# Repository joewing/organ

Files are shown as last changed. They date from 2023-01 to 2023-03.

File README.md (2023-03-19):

# 3D Printed Polyphonic Organ

## Features
  * Full-size 3D printed keyboard
  * 8-way polyphony
  * 9 drawbars to adjust harmonics (like a Hammond organ)
  * Sustain pedal
  * Range C0 through B7 (96 notes)

## Directories
  * src - Source code for the microcontroller (AVR ATtiny861A)
  * pcb/sensor - PCB for the key sensor board
  * pcb/controller PCB for the controller board
  * scad - OpenSCAD design

## Function Keys

Holding the "function" key on the controller PCB switches into
function mode.

### Tuning

Since we use the on-board oscillator, it is necessary to tune the
clock frequency to make the notes in tune. This tuning is stored in
EEPROM.

  * F#0 - Flatten
  * G#0 - Reset
  * A#0 - Sharpen

## 3D Printed Parts

  * Keybed
  * White keys (7)
  * Black keys (5)
  * Assembly tool (to help attach the rubber bands)
  * Control board holder

The sensor PCB is snapped into the keybed and the keys are attached,
one at a time along with the rubber band to pull the key up. Multiple
keybeds can be attached together using zipties (there are holes for
zipties in the standoff for the keys).

## BOM

  * Controller PCB
    * 1x ATtiny861A
    * 1x USB-B socket
    * 1x 2x3 IDC socket
    * 1x 3.5mm audio jack
    * 1x 3mm LED
    * 1x 6mm SPST tactile switch
    * 10x 10k linear POT
    * 2x 1k resistor
    * 12x 0.1u capacitor
    * 1x 10u capacitor
    * 1x 47u capacitor
    * 1x 6-pin right-angle socket

  * Sensor PCB (1 per octave)
    * 12x 12.6x6.5x5.7mm SPDT limit switch
    * 2x 10k resistor
    * 2x 74HC165
    * 2x 0.1uF capacitor
    * 1x 6-pin right-angle socket
    * 1x 6-pin right-angle pin header

  * Other
    * 12x small rubber bands (one set per octave)
    * USB cord and power supply

## Keys

Each note is controlled by a limit switch. The output of the limit
switches are processed serially using two 74HC165 8-bit parallel input
shift registers per octave. Since there are only 12 notes in an octave
4 bits are wasted for simplicity. Using this shift register interface,
we can read all keys using only 3 pins of the microcontroller.

In software, the state of each key is recorded in a bitmap. When a new key
press is detected, a "voice" is removed from the head of a linked list
and placed at the end of the list. The frequency increment is set
according to the index of the key that was pressed. The frequency increment
is a 16-bit value used to move through the waveform every time the
sample interrupt executes. The top 8 bits are used as an index into
the 256 entry waveform.

When a key release is detected, the "voice" is removed and placed at the
head of the list and the frequency increment is set to 0 to prevent the
sample interrupt from moving through the waveform.
The linked list is used so that the least recently pressed key is
re-used if there are too many keys pressed at the same time.

Finally, the sustain pedal simply prevents the processing of key releases.

## Drawbars

There are nine drawbars (potentiometers) that are sampled using the 
multiplexed ADC. One drawbar is sampled per iteration of the main loop.
We track the quantized value of each drawbar. When a change is
detected, its value is recorded and the waveform is recomputed.

## Waves

Waveforms are generated by sampling a 256 point sine wave.
The base waveform is at half the fundamental frequency (16')
allowing us to generate the necessary harmonics by stepping
through the sine wave at different rates:

  * 16'     - Sub-Octave (1x)
  * 5 1/3'  - Quint (3x)
  * 8'      - Principal (2x)
  * 4'      - Octave (4x)
  * 2 2/3'  - Nazard (6x)
  * 2'      - Super Octave (8x)
  * 1 3/5'  - Tierce (10x)
  * 1 1/3'  - Larigot (12x)
  * 1'      - Super-Super Octave (16x)

When a drawbar is changed, the waveform is recomputed by adding
together the scaled contributions from each drawbar. Each
contribution is determined by stepping through the sine wave at the
specified rate (2 for 8', etc), wrapping around when necessary,
and scaling the amplitude by the drawbar level. The final waveform
is scaled down by the max total contribution.
The waveform itself is stored as 256 8-bit values.

Audio is generated using 64 MHz pulse-width modulation. The duty cycle
is configured to have 256 levels, leaving an output frequency of 250 kHz,
which is well above the audio range and easy to filter. The duty cycle is
determined by adding together the waveform contributions from each voice.
Since there are 8 voices and the duty cycle is controlled by
an 8-bit value, we get 5 bits of resolution (this avoids overflow in
the case all voices are at the maximum position in the waveform at
the same time).
A 20 kHz timer interrupt causes us to move through the waveforms
for each voice and update the PWM duty cycle.

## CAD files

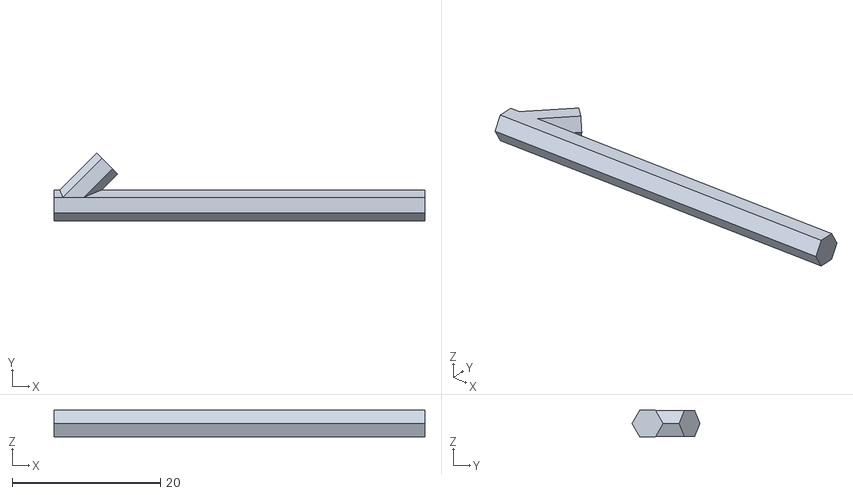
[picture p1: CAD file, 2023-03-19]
scad/tool.stl
50.0 x 9.17 x 3.64

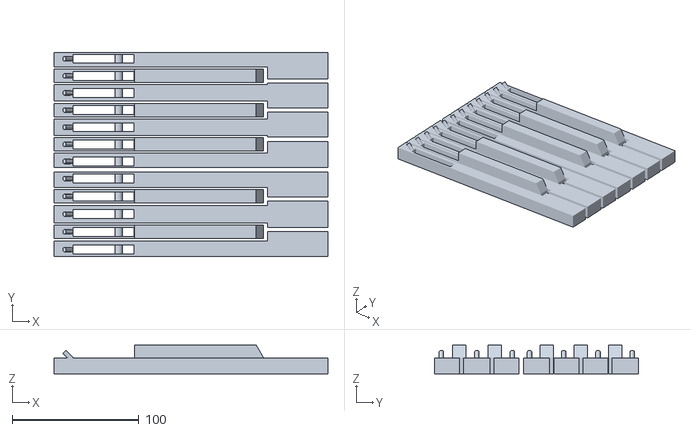
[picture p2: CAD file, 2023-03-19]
scad/keys.stl
216.0 x 160.8 x 22.9

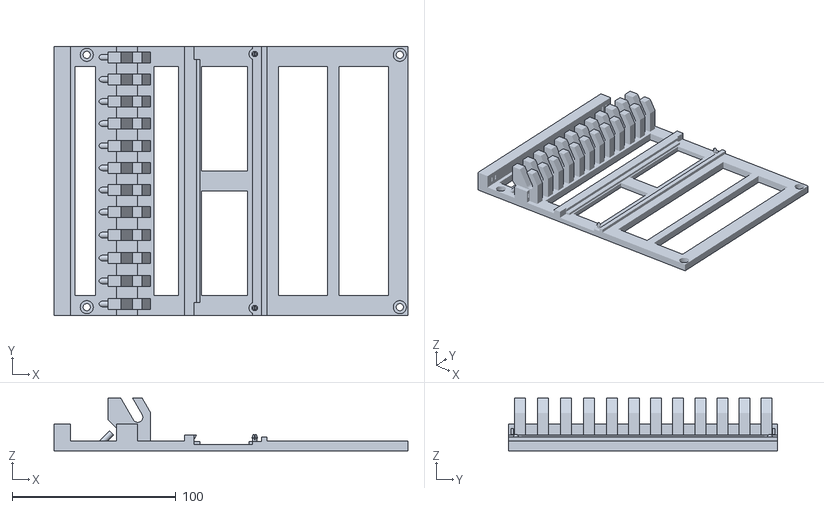
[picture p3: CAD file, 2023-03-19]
scad/bed.stl
216.0 x 164.0 x 32.3

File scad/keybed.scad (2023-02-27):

OUTPUT_KEYS = 0;
OUTPUT_BED = 1;
OUTPUT_BACK = 0;
OUTPUT_CONTROL = 0;
OUTPUT_TOOL = 0;

key_spacing = 3.2;
base_width = 164;

black_key_width = 14;
white_key_length = 216;
black_key_length = white_key_length - 2 * 25.4;
white_key_height = 0.5 * 25.4;
black_key_height = white_key_height + 0.4 * 25.4;
bed_height = 6;
bed_length = white_key_length;
joint_offset = 150;
screw_head_radius = 2.8;
screw_head_height = 3;
screw_hole_radius = 1.4;
pcb_length = 40;
pcb_thickness = 1.6;
pcb_mount_height = 2;
pcb_standoff_height = pcb_mount_height;
hinge_y = white_key_length - 54 + 3;
hinge_z = 4;
hinge_radius = 3;
pcb_offset = 90;
middle_hole_offset = 196;
key_elevation = 10.6;
bed_zoffset = -key_elevation - 0.2;
stop_height = white_key_height + key_elevation + 3;
cutout_width = 7;

white_key_widths = [23, 24, 23, 24, 23, 23, 24];
black_key_offsets = [14, 42, 83, 110, 137];

back_widths = [14, 14, 14, 14, 14, 13, 14, 13, 14, 13, 14, 13];

function white_key_offset(i) = i == 0 ? 0 : white_key_offset(i - 1) + white_key_widths[i - 1];

function back_offset(i) = i == 0 ? 0 : back_offset(i - 1) + back_widths[i - 1];

module stabilizer(i) {
    x = back_offset(i);
    w = back_widths[i];
    translate([x + w / 2 - cutout_width / 2, white_key_length - 63, -1]) { 
        cube([cutout_width, 48, black_key_height + 2]);
    }
}

module key_hinge(i) {
    x = back_offset(i);
    w = back_widths[i];
    translate([x + key_spacing / 2, hinge_y, hinge_z - 0.4]) {
        rotate([0, 90, 0]) {
            cylinder(w - key_spacing, hinge_radius, hinge_radius, $fn=64);
        }
    }
}

module band_holder(j) {
    x = back_offset(j);
    w = back_widths[j];
    y = white_key_length;
    translate([x + w / 2, y - 0.9 * 25.4 + 9, white_key_height - 4 + 3]) {
        rotate([-45, 0, 0]) cylinder(8, 1.8, 1.8, $fn=32);
    }
}

module white_key_cutout(i) {
    if(i >= 0) {
        x1 = black_key_offsets[i];
        x2 = x1 + black_key_width;
        translate([x1 - 0.01, 2 * 25.4 - key_spacing, -0.1]) {
            cube([x2 - x1 + 0.02, black_key_length * 2, black_key_height]); 
        }
    }
}

module white_key(i, j, cutout_left, cutout_right) {
    x = white_key_offset(i) + key_spacing / 2;
    w = white_key_widths[i] - key_spacing;
    difference() {
        union() {
            translate([x, 0, 0]) {
                cube([w, white_key_length, white_key_height]);
            }
            band_holder(j);
        }
        white_key_cutout(cutout_left);
        white_key_cutout(cutout_right);
        stabilizer(j);
    }
    key_hinge(j);
}

module black_key(i, j) {
    difference() {
        union() {
            translate([black_key_offsets[i] + key_spacing / 2, 2 * 25.4, 0]) {
                difference() {
                    cube([black_key_width - key_spacing, black_key_length, black_key_height]);
                    translate([-0.1, 4 * 25.4, white_key_height]) {
                        cube([black_key_width + 0.2, black_key_length, black_key_height]);
                    }
                    translate([-1, 0, black_key_height - 10]) {
                        rotate([60, 0, 0]) cube([black_key_width + 2, 100, 100]);
                    }
                } 
            }
            band_holder(j);
            key_hinge(j);
        }
        stabilizer(j);
    }
    key_hinge(j);
}

module white_keys() {
    white_key(0, 0, -1, 0);
    white_key(1, 2, 0, 1);
    white_key(2, 4, 1, -1);
    white_key(3, 5, -1, 2);
    white_key(4, 7, 2, 3);
    white_key(5, 9, 3, 4);
    white_key(6, 11, 4, -1);
}

module black_keys() {
    black_key(0, 1);
    black_key(1, 3);
    black_key(2, 6);
    black_key(3, 8);
    black_key(4, 10);
}

module keys() {
    white_keys();
    black_keys();
}

module key_stand(j) {
    x = back_offset(j);
    w = back_widths[j];
    
    // Stabilizer.
    difference() {
        translate([x, white_key_length - 59, 0]) {
            translate([w / 2 - cutout_width / 2 + 0.15, 0, 0]) {
                difference() {
                    cube([cutout_width - 0.15 * 2, 21 + 5, stop_height]);
                    translate([-1, 25, -5]) {
                        rotate([45, 0, 0]) cube([14, 22, 12]);        
                    }
                }
            }
            translate([0, 8, 0]) cube([w, 13, key_elevation]);
        }
        translate([x + w / 2 - cutout_width / 2, white_key_length - 59, stop_height]) {
            rotate([-30, 0, 0]) cube([15, 9, 20], center = true);
        }
        
        // Cut-out for hinge
        translate([x - 1, hinge_y - 0.1, key_elevation + hinge_z]) {
            rotate([-30, 0, 0]) translate([0, -hinge_radius - 0.1, 0]) cube([25, (hinge_radius + 0.1) * 2, 25]);
            rotate([0, 90, 0]) cylinder(20, hinge_radius + 0.1, hinge_radius + 0.1, $fn=64);
        }
    }

    // Rubber band holder
    translate([x + w / 2, white_key_length - 1.25 * 25.4 + 3, -1.3]) {
        rotate([45, 0, 0]) cylinder(9.1, 1.8, 1.8, $fn=32);
    }
}

module pcb_standoff(x, y) {
    base_radius = 4;
    standoff_radius = screw_head_radius * 1.25;
    translate([x, y, pcb_standoff_height]) {
        difference() {
            union() {
                translate([0, 0, -pcb_standoff_height]) {
                    cylinder(pcb_standoff_height, standoff_radius, standoff_radius, $fn=64);
                    translate([0, 0, pcb_standoff_height]) cylinder(d=screw_hole_radius * 2, h=pcb_thickness + 1, $fn=64);
                }
                translate([0, 0, pcb_thickness]) {
                    intersection() {
                        union() {
                            translate([0, 0, 0.5]) {
                                cylinder(d1 = screw_hole_radius * 2.5, d2 = screw_hole_radius * 1.5, h = 2, $fn=64);
                            }
                            cylinder(d1 = screw_hole_radius * 2, d2 = screw_hole_radius * 2.5, h = 0.5, $fn=64);
                        }
                        cube([screw_hole_radius * 2, base_radius * 2, base_radius * 2], center=true);
                    }
                }
            }
            translate([0, 0, (pcb_thickness + 20) / 2])cube([20, 0.5, 20], center=true);
        }
    }
}

module pcb_mount() {
    translate([0, 0, -pcb_standoff_height - 0.1]) {
        pcb_standoff(3.5 + 1, pcb_offset + 3.5);
        pcb_standoff(base_width - 3.5 - 1, pcb_offset + 3.5);
        translate([0, pcb_offset - 1]) cube([base_width, 6, pcb_standoff_height]);
        translate([8, pcb_offset + pcb_length - 3]) cube([base_width - 16, 4, pcb_standoff_height]);
    }
    translate([8, pcb_offset + pcb_length + 2.5, pcb_thickness]) rotate([0, 90, 0]) {
        cylinder(base_width - 16, 4, 4, $fn=3);
    }
    translate([0, pcb_offset + pcb_length + 0.5, pcb_thickness - 3]) {
        cube([base_width, 6, 5]);
    }
    translate([0, pcb_offset - 4, 0]) {
        cube([base_width, 4 - 0.5, pcb_thickness + 1]);
    }
}

module screw_hole(x, y) {
    translate([x, y, -bed_height - 1]) {
        cylinder(bed_height + 2, 2.2, 2.2, $fn=32);
        translate([0, 0, screw_head_height]) cylinder(bed_height, 4, 4, $fn=32);
    }
}

mounting_hole_positions = [
    [base_width - 5, 5],
    [5, 5],
    [base_width - 5, middle_hole_offset],
    [5, middle_hole_offset]
];
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

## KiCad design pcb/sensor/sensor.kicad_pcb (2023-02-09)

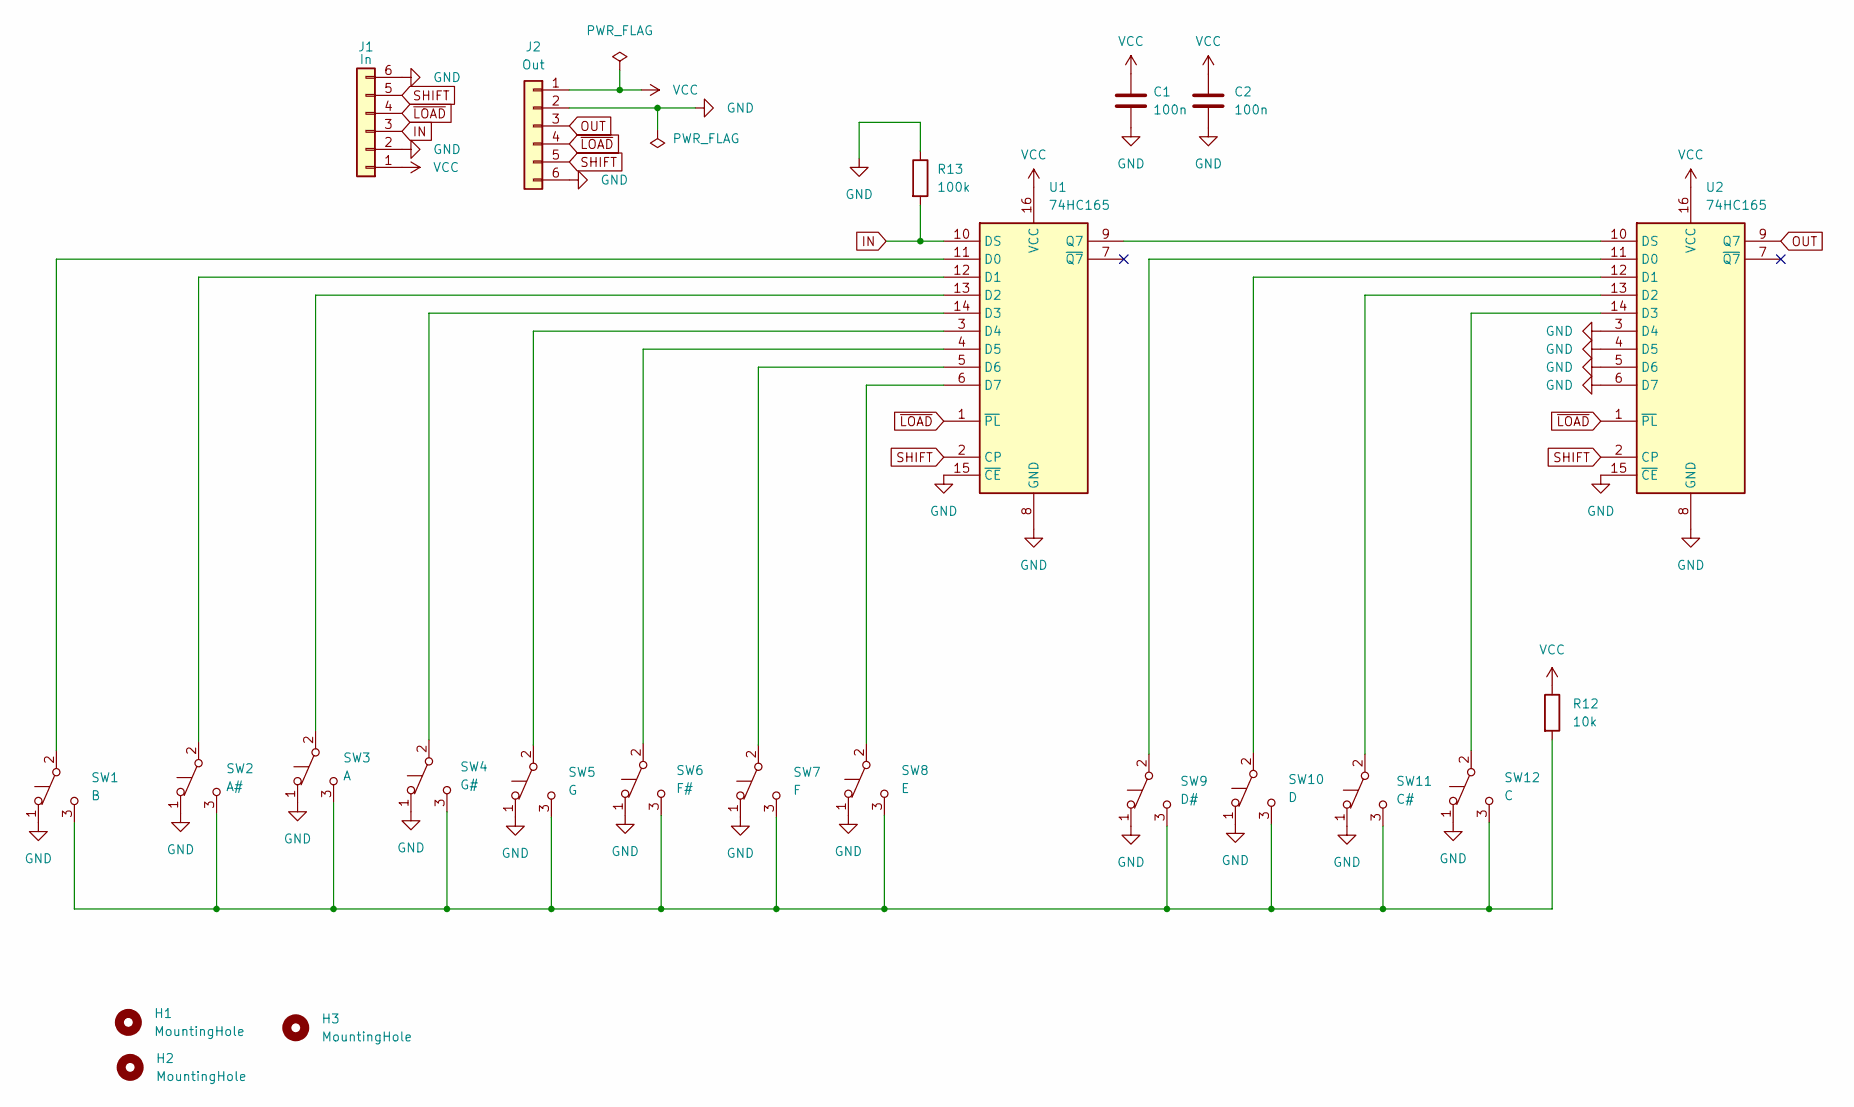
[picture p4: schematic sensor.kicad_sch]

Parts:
C1, C2: 100n; C_Disc_D3.0mm_W2.0mm_P2.50mm
H1, H2, H3: MountingHole; MountingHole_3.2mm_M3
J1: In; PinHeader_1x06_P2.54mm_Vertical
J2: Out; PinHeader_1x06_P2.54mm_Vertical
R12: 10k; R_Axial_DIN0207_L6.3mm_D2.5mm_P10.16mm_Horizontal
R13: 100k; R_Axial_DIN0207_L6.3mm_D2.5mm_P10.16mm_Horizontal
SW1: B; Mini Limit Switch
SW2: A#; Mini Limit Switch
SW3: A; Mini Limit Switch
SW4: G#; Mini Limit Switch
SW5: G; Mini Limit Switch
SW6: F#; Mini Limit Switch
SW7: F; Mini Limit Switch
SW8: E; Mini Limit Switch
SW9: D#; Mini Limit Switch
SW10: D; Mini Limit Switch
SW11: C#; Mini Limit Switch
SW12: C; Mini Limit Switch
U1, U2: 74HC165; DIP-16_W7.62mm_Socket

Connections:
GND: C1.2, C2.2, J1.2, J1.6, J2.2, J2.6, R13.1, SW1.1 (A), SW2.1 (A), SW3.1 (A), SW4.1 (A), SW5.1 (A), SW6.1 (A), SW7.1 (A), SW8.1 (A), SW9.1 (A), SW10.1 (A), SW11.1 (A), SW12.1 (A), U1.8 (GND), U1.15 (~CE), U2.3 (D4), U2.4 (D5), U2.5 (D6), U2.6 (D7), U2.8 (GND), U2.15 (~CE)
IN: J1.3, R13.2, U1.10 (DS)
unnamed: R12.2, SW1.3 (C), SW2.3 (C), SW3.3 (C), SW4.3 (C), SW5.3 (C), SW6.3 (C), SW7.3 (C), SW8.3 (C), SW9.3 (C), SW10.3 (C), SW11.3 (C), SW12.3 (C)
unnamed: SW1.2 (B), U1.11 (D0)
unnamed: SW2.2 (B), U1.12 (D1)
unnamed: SW3.2 (B), U1.13 (D2)
unnamed: SW4.2 (B), U1.14 (D3)
unnamed: SW5.2 (B), U1.3 (D4)
unnamed: SW6.2 (B), U1.4 (D5)
unnamed: SW7.2 (B), U1.5 (D6)
unnamed: SW8.2 (B), U1.6 (D7)
unnamed: SW9.2 (B), U2.11 (D0)
unnamed: SW10.2 (B), U2.12 (D1)
unnamed: SW11.2 (B), U2.13 (D2)
unnamed: SW12.2 (B), U2.14 (D3)
unnamed: U1.9 (Q7), U2.10 (DS)
OUT: J2.3, U2.9 (Q7)
SHIFT: J1.5, J2.5, U1.2 (CP), U2.2 (CP)
VCC: C1.1, C2.1, J1.1, J2.1, R12.1, U1.16 (VCC), U2.16 (VCC)
~LOAD: J1.4, J2.4, U1.1 (~PL), U2.1 (~PL)

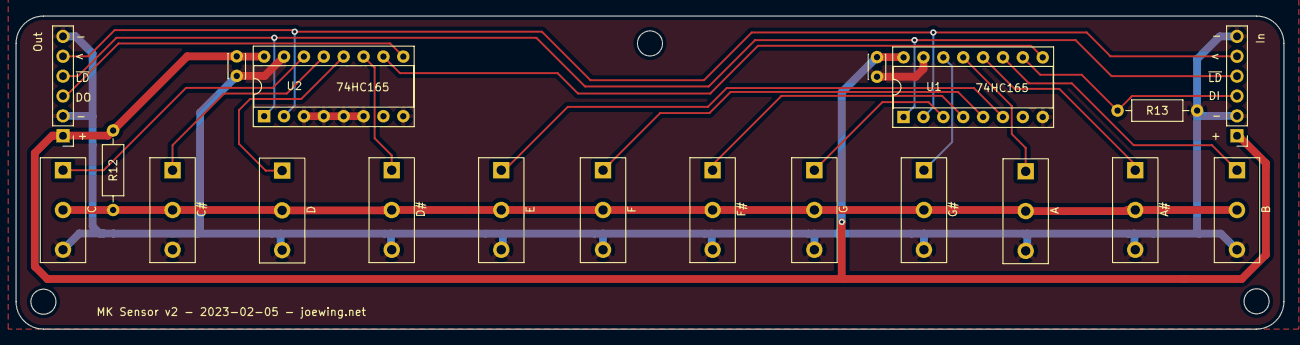
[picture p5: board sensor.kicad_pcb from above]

Board: 2 copper layers, 162.0 x 40.0 mm, 23 parts (0 on the bottom side), 20 nets.

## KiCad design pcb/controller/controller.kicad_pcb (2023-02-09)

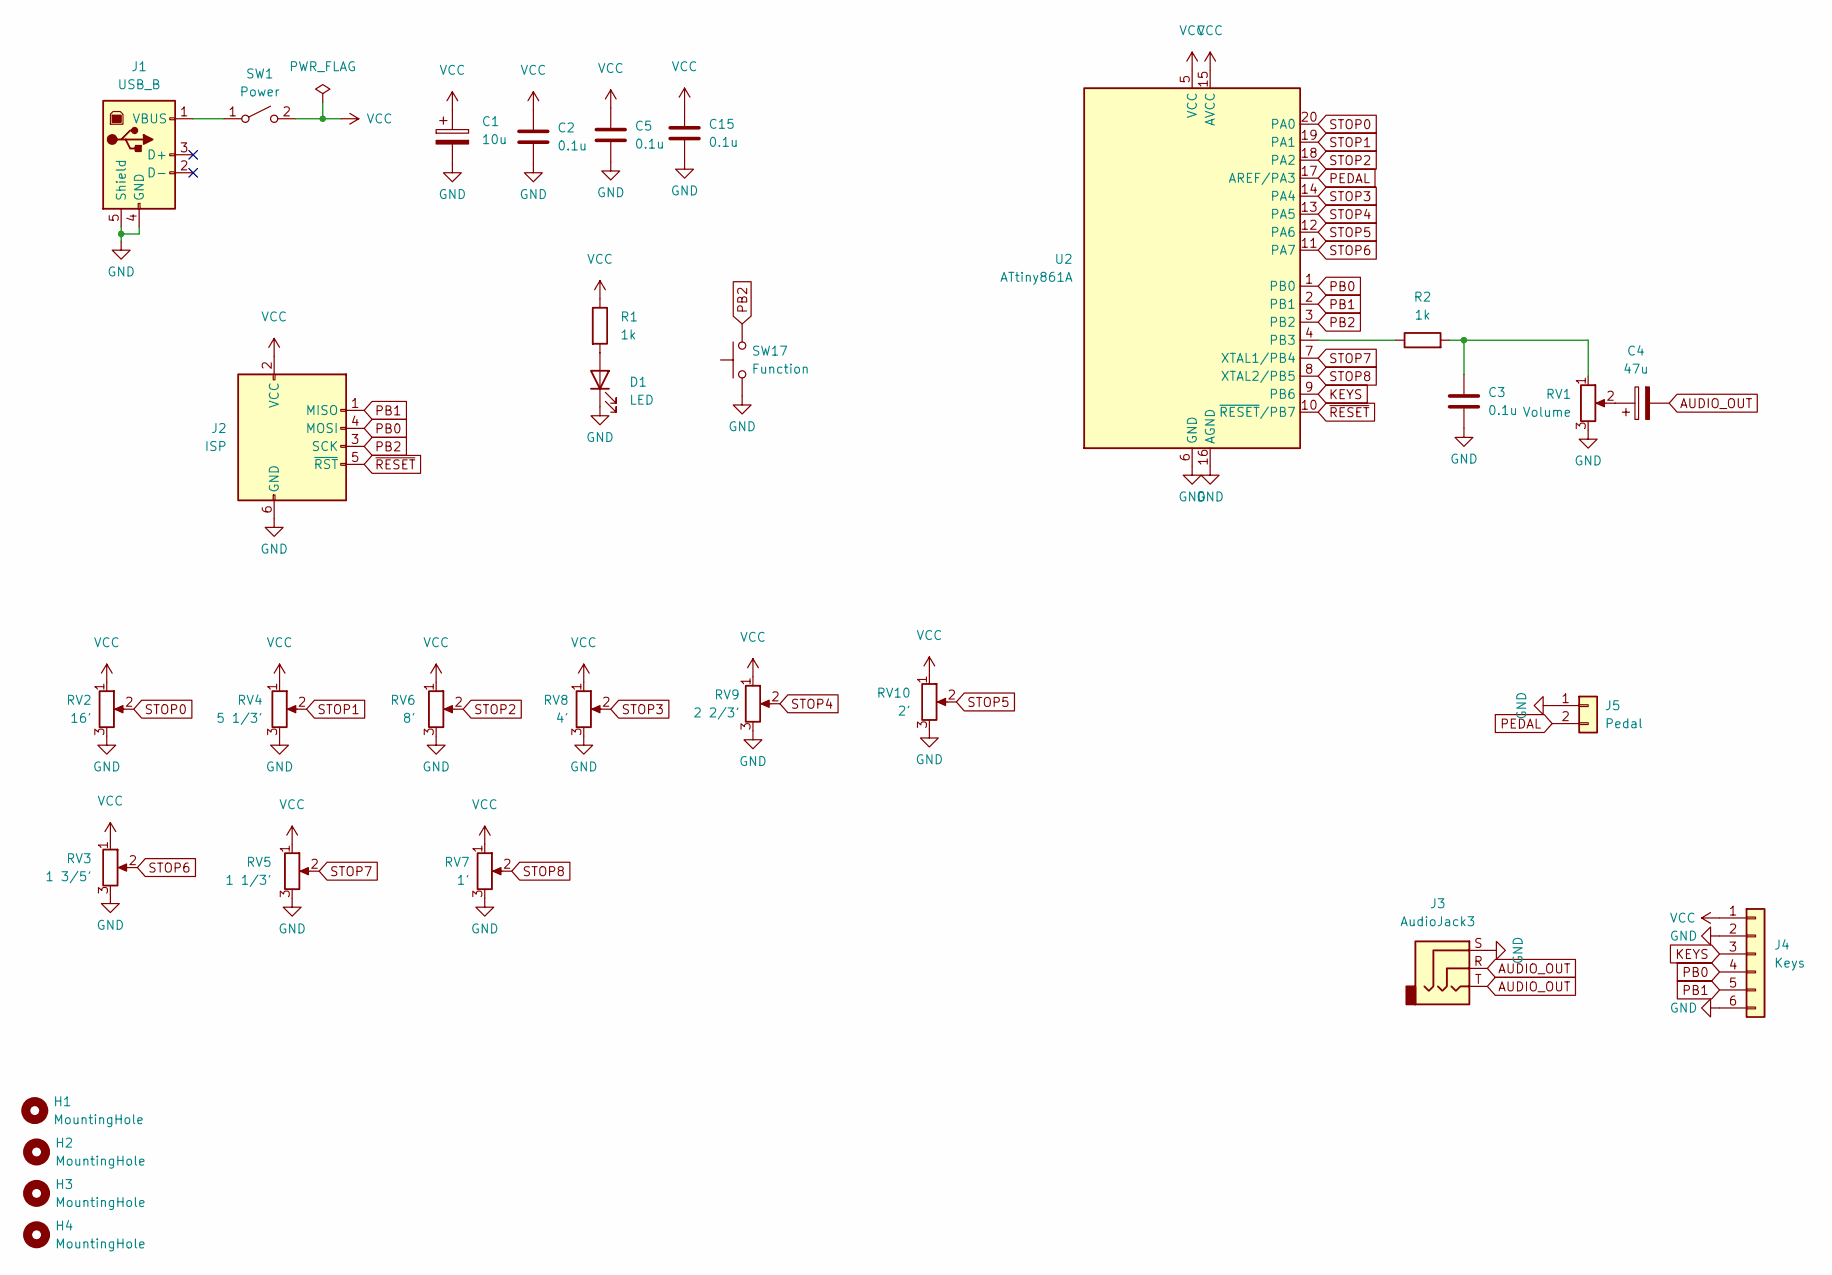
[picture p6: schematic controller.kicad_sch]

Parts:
C1: 10u; CP_Radial_D5.0mm_P2.00mm; LCSC C15850
C2, C3, C5, C15: 0.1u; C_Disc_D3.0mm_W2.0mm_P2.50mm; LCSC C49678
C4: 47u; CP_Radial_D5.0mm_P2.00mm; LCSC C15850
D1: LED; LED_D3.0mm; LCSC C2297
H1, H2, H3, H4: MountingHole; MountingHole_3.2mm_M3
J1: USB_B; USB_B_OST_USB-B1HSxx_Horizontal
J2: ISP; IDC-Header_2x03_P2.54mm_Vertical
J3: AudioJack3; Jack_3.5mm_CUI_SJ1-3523N_Horizontal
J4: Keys; PinHeader_1x06_P2.54mm_Vertical
J5: Pedal; PinHeader_1x02_P2.54mm_Vertical
R1, R2: 1k; R_Axial_DIN0309_L9.0mm_D3.2mm_P15.24mm_Horizontal; LCSC C17513
RV1: Volume; Potentiometer_Bourns_PTA3043_Single_Slide
RV2: 16'; Potentiometer_Bourns_PTA3043_Single_Slide
RV3: 1 3/5'; Potentiometer_Bourns_PTA3043_Single_Slide
RV4: 5 1/3'; Potentiometer_Bourns_PTA3043_Single_Slide
RV5: 1 1/3'; Potentiometer_Bourns_PTA3043_Single_Slide
RV6: 8'; Potentiometer_Bourns_PTA3043_Single_Slide
RV7: 1'; Potentiometer_Bourns_PTA3043_Single_Slide
RV8: 4'; Potentiometer_Bourns_PTA3043_Single_Slide
RV9: 2 2/3'; Potentiometer_Bourns_PTA3043_Single_Slide
RV10: 2'; Potentiometer_Bourns_PTA3043_Single_Slide
SW1: Power; PinHeader_1x03_P2.54mm_Vertical
SW17: Function; SW_PUSH_6mm
U2: ATtiny861A; DIP-20_W7.62mm

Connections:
AUDIO_OUT: C4.2, J3.R, J3.T
GND: C1.2, C2.2, C3.2, C5.2, C15.2, D1.1 (K), J1.4 (GND), J1.5 (Shield), J2.6 (GND), J3.S, J4.2, J4.6, J5.1, RV1.3, RV2.3, RV3.3, RV4.3, RV5.3, RV6.3, RV7.3, RV8.3, RV9.3, RV10.3, SW17.1, U2.6 (GND), U2.16 (AGND)
KEYS: J4.3, U2.9 (PB6)
unnamed: C3.1, R2.2, RV1.1
unnamed: C4.1, RV1.2
unnamed: D1.2 (A), R1.2
unnamed: J1.1 (VBUS), SW1.1 (A)
unnamed: R2.1, U2.4 (PB3)
PB0: J2.4 (MOSI), J4.4, U2.1 (PB0)
PB1: J2.1 (MISO), J4.5, U2.2 (PB1)
PB2: J2.3 (SCK), SW17.2, U2.3 (PB2)
PEDAL: J5.2, U2.17 (AREF/PA3)
STOP0: RV2.2, U2.20 (PA0)
STOP1: RV4.2, U2.19 (PA1)
STOP2: RV6.2, U2.18 (PA2)
STOP3: RV8.2, U2.14 (PA4)
STOP4: RV9.2, U2.13 (PA5)
STOP5: RV10.2, U2.12 (PA6)
STOP6: RV3.2, U2.11 (PA7)
STOP7: RV5.2, U2.7 (XTAL1/PB4)
STOP8: RV7.2, U2.8 (XTAL2/PB5)
VCC: C1.1, C2.1, C5.1, C15.1, J2.2 (VCC), J4.1, R1.1, RV2.1, RV3.1, RV4.1, RV5.1, RV6.1, RV7.1, RV8.1, RV9.1, RV10.1, SW1.2 (B), U2.5 (VCC), U2.15 (AVCC)
~RESET: J2.5 (~RST), U2.10 (~RESET/PB7)

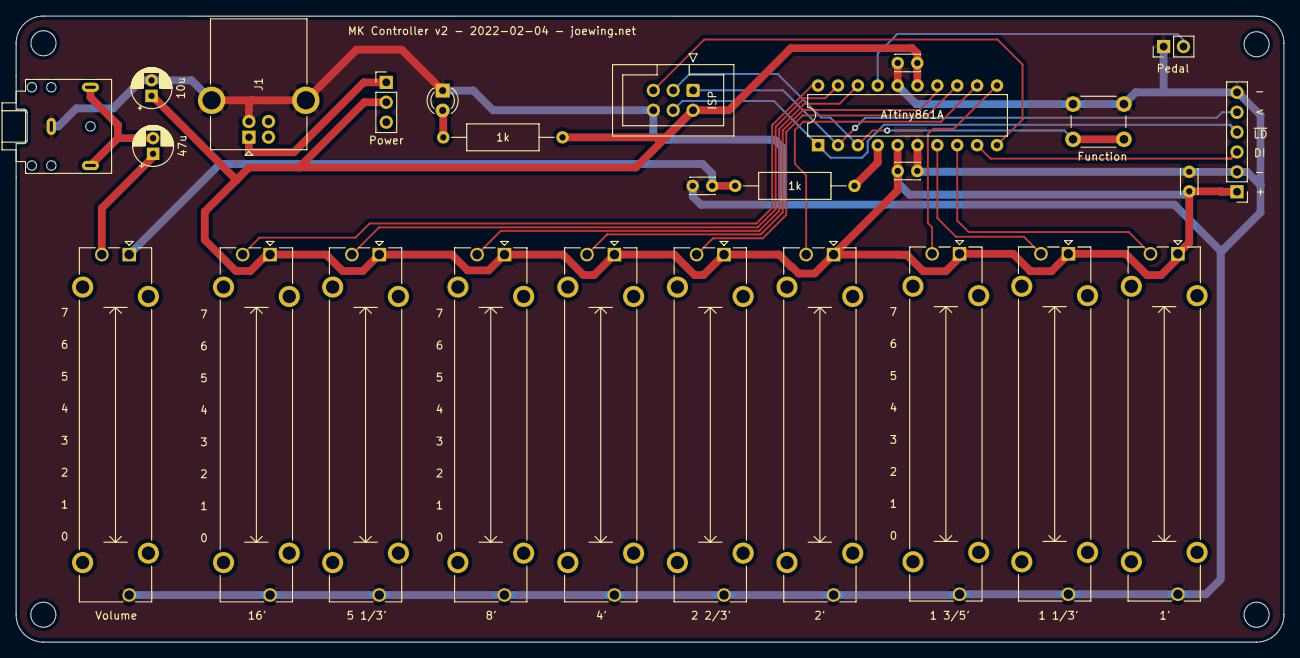
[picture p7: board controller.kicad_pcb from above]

Board: 2 copper layers, 162.0 x 80.0 mm, 31 parts (0 on the bottom side), 23 nets.

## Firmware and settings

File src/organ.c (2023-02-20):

/* Polyphonic Drawbar Organ for the ATtiny861
 * Joe Wingbermuehle
 * 2023-02-11
 */

#include <avr/pgmspace.h>
#include <avr/io.h>
#include <avr/interrupt.h>
#include <avr/eeprom.h>

#if defined(__AVR_ATtiny861A__) || defined(__AVR_ATtiny861__)
#   define ATTINY861A
#else
#   define ATTINY85
#endif

#include <stdint.h>
#include <string.h>

#include "freq.h"
#include "wave.h"

#define VOICE_BITS        3       // 2^n voices at the same time
#define OCTAVE_COUNT      6       // Number of physcial octaves
#define INITIAL_OCTAVE    1       // Initial lowest physical octave

#ifdef ATTINY861A
#define KEY_LATCH_PIN PB0
#define KEY_CLOCK_PIN PB1
#define FUN_INPUT_PIN PB2
#define AUDIO_OUT_PIN PB3
#define KEY_INPUT_PIN PB6
#else
#define KEY_LATCH_PIN PB0
#define KEY_CLOCK_PIN PB1
#define FUN_INPUT_PIN PB2
#define KEY_INPUT_PIN PB3
#define AUDIO_OUT_PIN PB4
#endif

#define VOICE_COUNT         (1 << VOICE_BITS)
#define KEY_BYTES           (OCTAVE_COUNT * 2)  // 2 bytes per octave
#define TUNING_KEY          (A4_INDEX - INITIAL_OCTAVE * 16) // Key index of A4
#define TUNING_EEPROM_ADDR  (uint8_t*)0x00
#define TUNING_COOKIE       0xA4

// Number of steps to move through the waveform each beat.
// In the order of Hammond drawbars:
const static uint8_t __flash STEPS[] = {
  1,    // 16'
  3,    // 5 1/3'
  2,    // 8'
  4,    // 4'
  6,    // 2 2/3'
  8,    // 2'
  10,   // 1 3/5'
  12,   // 1 1/3'
  16,   // 1
};
#define DRAWBAR_COUNT (sizeof(STEPS) / sizeof(STEPS[0]))

typedef struct Voice {
  struct Voice *next;
  struct Voice *prev;
  uint16_t timer;             // Index into the wave table
  volatile uint16_t freq;     // Increment for the timer (0 if off)
  uint8_t key_index;          // Key index (0 if off)
} Voice;

static uint8_t tuning_updated;         // Set if tuning needs to be saved
static Voice voices[VOICE_COUNT];
static Voice *voice_head;             // Next voice to use
static uint8_t key_state[KEY_BYTES];
static uint8_t wave[256];
static uint8_t drawbars[DRAWBAR_COUNT];

ISR(TIMER0_COMPA_vect)
{
  uint16_t mix = 0;
  for(Voice *vp = voices; vp != &voices[VOICE_COUNT]; vp++) {
    const uint8_t wave_index = (uint8_t)(vp->timer >> 8);
    mix += wave[wave_index];
    vp->timer += vp->freq;
  }
  OCR1B = (uint8_t)(mix >> VOICE_BITS);
}

static void press_key(uint8_t key_index)
{
  const uint8_t freq_index = key_index + (INITIAL_OCTAVE * 16);

  // Take a voice from the head of the list and put it on the tail
  // (head->prev). Note that we don't mark the key as released so that
  // it doesn't get re-pressed until it is actually released.
  Voice *vp = voice_head;
  voice_head = vp->next;

  vp->freq = FREQUENCIES[freq_index];
  vp->key_index = key_index;
  key_state[key_index >> 3] |= 1 << (key_index & 7);
}

static void release_key(uint8_t key_index)
{
  for(Voice *vp = voices; vp != &voices[VOICE_COUNT]; vp++) {
    if(vp->key_index == key_index) {
      vp->freq = 0;
      vp->key_index = 0;

      // Remove the voice from it's position in the list and
      // place it at the head.
      if(vp != voice_head) {
        vp->prev->next = vp->next;
        vp->next->prev = vp->prev;
        vp->prev = voice_head->prev;
        vp->next = voice_head;
        voice_head->prev->next = vp;
        voice_head->prev = vp;
        voice_head = vp;
      }
      break;
    }
  }
  key_state[key_index >> 3] &= ~(1 << (key_index & 7));
}

static void release_all_keys()
{
  memset(key_state, 0, sizeof(key_state));

  voice_head = NULL;
  for(Voice *vp = voices; vp != &voices[VOICE_COUNT]; vp++) {
    vp->freq = 0;
    vp->key_index = 0;
    if(voice_head) {
      vp->prev = voice_head->prev;
      vp->next = voice_head;
      voice_head->prev->next = vp;
      voice_head->prev = vp;
    } else {
      vp->next = vp;
      vp->prev = vp;
    }
    voice_head = vp;
  }
}

static void press_tuning_key()
{
  release_all_keys();
  press_key(TUNING_KEY);
}

static void read_tuning()
{
  if(eeprom_read_byte(TUNING_EEPROM_ADDR + 1) == TUNING_COOKIE) {
    OSCCAL = eeprom_read_byte(TUNING_EEPROM_ADDR);
  }
  tuning_updated = 0;
}

static void write_tuning()
{
  if(tuning_updated) {
    eeprom_write_byte(TUNING_EEPROM_ADDR, OSCCAL);
    eeprom_write_byte(TUNING_EEPROM_ADDR + 1, TUNING_COOKIE);
    tuning_updated = 0;
  }
}

static void update_wave()
{

  // Compute an upper bound on the total mixture.
  uint8_t total_mixture = 0;
  for(const uint8_t *dp = drawbars; dp != &drawbars[DRAWBAR_COUNT]; dp++) {
    total_mixture += *dp;
  }
  if(total_mixture == 0) total_mixture = 1;

  // Disable interrupts before updating the waveform to avoid pops.
  const uint8_t t = SREG;
  cli();

  // Create the new waveform using our initial guess for the amplitude.
  uint8_t max_value = 0;
  uint8_t min_value = 255;
  uint8_t current_index[DRAWBAR_COUNT] = { 0 };
  for(uint8_t *wp = wave; wp != &wave[256]; wp++) {

    // Add in the contribution from each drawbar.
    uint16_t mixture = 0;
    for(uint8_t h = 0; h < DRAWBAR_COUNT; h++) {
      const uint8_t wave_index = current_index[h];
      mixture += SINE_WAVE[wave_index] * drawbars[h];
      current_index[h] += STEPS[h];
    }

    // Store the scaled mixture to the waveform.
    *wp = (uint8_t)(mixture / total_mixture);
    if(*wp > max_value) max_value = *wp;
    if(*wp < min_value) min_value = *wp;
  }

  // Scale up to the full amplitude.
  const uint8_t scale = 255 - max_value + min_value;
  for(uint8_t *wp = wave; wp != &wave[256]; wp++) {
    const uint16_t unscaled = *wp - min_value;
    const uint16_t scaled = (unscaled << 8) + (unscaled * scale);
    *wp = (uint8_t)(scaled >> 8);
  }

  // Restore interrupts.
  SREG = t;
}

#ifndef ATTINY861A
static void update_stop(uint8_t i)
{
  drawbars[i] ^= 1;
  update_wave();
}
#endif

#ifdef ATTINY861A
static void update_drawbars()
{
  if(!(ADCSRA & (1 << ADSC))) {
    const uint8_t index = ADMUX & 31;
    const uint8_t next_index = index + 1;
    const uint8_t value = (uint8_t)ADCH >> 5;
    if(value != drawbars[index]) {
      drawbars[index] = value;
      update_wave();
    }

    // Next input.
    ADMUX = (0 << REFS0) 
          | (1 << ADLAR)
          | ((next_index >= DRAWBAR_COUNT) ? 0 : next_index);
    ADCSRA |= (1 << ADSC);  // Start
  }
}
#endif

static void set_mode(uint8_t i)
{
  i -= 4;   // First 4 are blank.
  switch(i) {

#ifndef ATTINY861A
  case 0:   // C
    update_stop(2);
    break;
  case 2:   // D
    update_stop(3);
    break;
  case 4:   // E
    update_stop(4);
    break;
  case 5:   // F
    update_stop(5);
    break;
  case 7:   // G
    update_stop(6);
    break;
  case 9:   // A
    update_stop(7);
    break;
  case 11:  // B
    update_stop(8);
    break;
  case 1: // C#
    update_stop(0);
    break;
  case 3: // D#
    update_stop(1);
    break;
#endif


  case 6: // F# (flatten)
    if(OSCCAL > 0) {
      OSCCAL -= 1;
      tuning_updated = 1;
    }
    break;
  case 8: // G# (reset tuning)
#ifndef ATTINY861A
    memset(drawbars, 0, sizeof(drawbars));
    update_wave();
#endif
    read_tuning();
    break;
  case 10: // A# (sharpen)
#ifdef ATTINY861A
    if(OSCCAL < 255) {
      OSCCAL += 1;
      tuning_updated = 1;
    }
#else
    if(OSCCAL < 127) {
      OSCCAL += 1;
      tuning_updated = 1;
    }
#endif
    break;
  default:
    break;
  }
  press_tuning_key();
}

static void scan()
{
  static uint8_t control_pressed = 0;
  uint8_t has_press = 0;
  uint8_t key_index = 0;

  // Pull the load enable high to hold values.
  PORTB |= 1 << KEY_LATCH_PIN;

  const uint8_t control = (~PINB) & (1 << FUN_INPUT_PIN);
#ifdef ATTINY861A
  const uint8_t sustain = (~PINA) & (1 << PA3);
#else
  const uint8_t sustain = 0;
#endif
  for(uint8_t i = 0; i < KEY_BYTES; i++) {
    const uint8_t state = key_state[i];
    for(uint8_t mask = 0x01; mask; mask <<= 1) {

      // Bring clock low so we shift on the next clock.
      PORTB &= ~(1 << KEY_CLOCK_PIN);

      const uint8_t input = PINB & (1 << KEY_INPUT_PIN);
      if(control) {
        if(input) {
          if(!control_pressed) {
            set_mode(key_index);
            control_pressed = 1;
          }
          has_press = 1;
        }
      } else {
        const uint8_t current = state & mask;
        if(input && !current) {
          press_key(key_index);
        } else if(!input && current && !sustain) {
          release_key(key_index);
        }
      }

      // Pull clock high to cause a shift.
      PORTB |= 1 << KEY_CLOCK_PIN;

      key_index += 1;
    }
  }
  control_pressed &= has_press;
  if(!control && tuning_updated) write_tuning();

  // Pull load enable low to load new values.
  PORTB &= ~(1 << KEY_LATCH_PIN);
}

static void init()
{
  release_all_keys();
  memset(drawbars, 0, sizeof(drawbars));
#ifndef ATTINY861A
  drawbars[2] = 1;
  drawbars[3] = 1;
#endif
  read_tuning();
  update_wave();
}

int main()
{
  cli();

#ifdef ATTINY861A

  // Clock prescalar
  // Default is 1MHz, switch to 8MHz
  CLKPR = 1 << CLKPCE;
  CLKPR = 0;

  // Enable PLL.
  PLLCSR |= (1 << PLLE);

  // Set input pullups and output state.
  PORTA = (1 << PA3);
  PORTB = (1 << KEY_INPUT_PIN)
        | (1 << FUN_INPUT_PIN);

  // Set outputs.
  DDRA = 0;
  DDRB = (1 << KEY_LATCH_PIN)
       | (1 << KEY_CLOCK_PIN)
       | (1 << AUDIO_OUT_PIN);

  // PWM timer setup (timer1)
  // This timer uses high-frequency PWM to generate the amplitude of
  // the wave based on the duty cycle set in OCR1B.
  PLLCSR |= (1 << PCKE);                  // 64MHz PLL source for timer1
  TCCR1A  = (2 << COM1B0)                 // Clear on match, OC1B
          | (1 << PWM1B);                 // PWMB
  TCCR1B = (1 << CS10);                   // 1:1 prescalar
  TCCR1D = (0 << WGM10);                  // Fast PWM
  OCR1C = 255;                            // Divide by 256 -> 250 kHz
  OCR1B = 0;                              // Duty cycle
  
  // Tone generator timer setup (timer0)
  // This timer invokes an interrupt to move through the waveforms
  // and update the duty cycle of timer1.
  // Clock is 8MHz, set prescaler to 8 and divide by 50 to get 20kHz
  TCCR0A = 1;                             // 8-bit, waveform mode.
  TCCR0B = (2 << CS00);                   // Divide by 8
  OCR0A = 50 - 1;                         // Divide by 50.
  TIMSK = 1 << OCIE0A;                    // Enable compare match interrupt

  // Set up ADC for drawbars.
  ADMUX   = (0 << REFS0)  // Vcc reference
          | (1 << ADLAR)  // Left adjust (we only need 8 bits of resolution)
          | (0 << MUX0);  // ADC0 - PA0
  ADCSRA  = (1 << ADEN)   // Enable ADC
          | (0 << ADSC)   // Don't start yet.
          | (0 << ADATE)  // Disable auto-trigger
          | (0 << ADIE)   // Disable interupt
          | (7 << ADPS0); // Divide by 128
  DIDR0   = (1 << ADC0D)  // Disable digital input for ADC0 - PA0
          | (1 << ADC1D)  // Disable digital input for ADC1 - PA1
          | (1 << ADC2D)  // Disable digital input for ADC2 - PA2
          | (0 << AREFD)  // Enable digital input for  AREF - PA3
          | (1 << ADC3D)  // Disable digital input for ADC3 - PA4
          | (1 << ADC4D)  // Disable digital input for ADC4 - PA5
          | (1 << ADC5D)  // Disable digital input for ADC5 - PA6
          | (1 << ADC6D); // Disable digital input for ADC6 - PA7
  DIDR1   = (1 << ADC7D)  // Disable digital input for ADC7 - PB4
          | (1 << ADC8D); // Disable digital input for ADC8 - PB5
  ADCSRA |= (1 << ADSC);  // Start

#else

  // Clock prescalar
  // Default is 1MHz, switch to 8MHz
  CLKPR = 1 << CLKPCE;
  CLKPR = 0;

  // Set input pullups and output state.
  PORTB = (1 << FUN_INPUT_PIN);

  // Set outputs.
  DDRB = (1 << KEY_LATCH_PIN)
       | (1 << KEY_CLOCK_PIN)
       | (1 << AUDIO_OUT_PIN);

  // PWM timer setup (timer1)
  PLLCSR = (1 << PCKE) | (1 << PLLE);   // 64MHz PLL source for timer1
  TIMSK = 0;                            // Timer interrupts off
  TCCR1 = 1 << CS10;                    // 1:1 prescalar
  GTCCR = (1 << PWM1B) | (2 << COM1B0); // PWM B, Clear on match
  OCR1C = 255;                          // Divide by 256 -> 250 kHz
  OCR1B = 0;                            // Duty cycle
  
  // Tone generator timer setup (timer0)
  // Clock is 8MHz, set prescaler to 8 and divide by 50 to get 20kHz
  TCCR0A = 3 << WGM00;                  // Fast PWM
  TCCR0B = (1 << WGM02) | (2 << CS00);  // Waveform, divide by 8
  OCR0A = 50 - 1;                       // Divide by 50.
  TIMSK = 1 << OCIE0A;                  // Enable compare match interrupt

#endif

  init();

  sei();

  for(;;) {
    scan();
#ifdef ATTINY861A
    update_drawbars();
#endif
  }

  return 0;
}

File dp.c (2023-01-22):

#include <avr/pgmspace.h>
#include <avr/io.h>
#include <avr/interrupt.h>
#include <stdint.h>

#include "freq.h"
#include "wave.h"

#define VOICE_BITS        3
#define KEY_BYTES         (2 * 1)
#define INITIAL_TUNING    0
#define FREQ_OFFSET       (68 - 4)

#define INSTRUMENT_COUNT  (sizeof(WAVE) / sizeof(WAVE[0]))
#define VOICE_COUNT       (1 << VOICE_BITS)

#define KEY_LATCH_PIN PB0
#define KEY_CLOCK_PIN PB1
#define FUN_INPUT_PIN PB2
#define KEY_INPUT_PIN PB3
#define AUDIO_OUT_PIN PB4

typedef struct Voice {
  volatile uint16_t timer;
  volatile uint16_t freq;
  uint8_t freq_index;
} Voice;

static volatile uint8_t instrument;
static int8_t tuning;
static uint8_t control_pressed;
static Voice voices[VOICE_COUNT];
static uint8_t key_state[KEY_BYTES];

ISR(TIMER0_COMPA_vect)
{
  uint16_t mix = 0;
  for(uint8_t vi = 0; vi < VOICE_COUNT; vi++) {
    const uint16_t timer = voices[vi].timer;
    const uint8_t wave_index = timer >> 8;
    mix += WAVE[instrument][wave_index];
    voices[vi].timer = voices[vi].freq + timer;
  }
  OCR1B = (uint8_t)(mix >> VOICE_BITS);
}

static void press_key(uint8_t freq_index)
{
  for(uint8_t i = 0; i < VOICE_COUNT; i++) {
    if(voices[i].freq_index == 0) {
      voices[i].timer = 0;
      voices[i].freq = FREQUENCIES[freq_index] + tuning;
      voices[i].freq_index = freq_index;
      break;
    }
  }
}

static void release_key(uint8_t freq_index)
{
  for(uint8_t i = 0; i < VOICE_COUNT; i++) {
    if(voices[i].freq_index == freq_index) {
      voices[i].freq = 0;
      voices[i].freq_index = 0;
      break;
    }
  }
}

static void set_mode(uint8_t i)
{
  i -= FREQ_OFFSET + 4;   // First 4 are blank.
  switch(i) {
  case 0: // C
    instrument = TRIANGLE_WAVE;
    break;
  case 2: // D
    instrument = SINE_WAVE;
    break;
  case 4: // E
    instrument = SQUARE_WAVE;
    break;
  case 5: // F
    instrument = SAWTOOTH_WAVE;
    break;
  case 1: // C# (flatten)
    if(tuning > -128) {
      tuning -= 1;
    }
    break;
  case 3: // D# (sharpen)
    if(tuning < 127) {
      tuning += 1;
    }
    break;
  case 6: // F# (reset tuning)
    tuning = INITIAL_TUNING;
    break;
  default:
    break;
  }
}

static void scan()
{
  uint8_t freq_index = FREQ_OFFSET;

  // Pull the load enable high to hold values.
  PORTB |= 1 << KEY_LATCH_PIN;

  const uint8_t control = (~PINB) & (1 << FUN_INPUT_PIN);
  for(uint8_t i = 0; i < KEY_BYTES; i++) {
    uint8_t state = key_state[i];
    for(uint8_t mask = 0x80; mask; mask >>= 1) {

      // Bring clock low so we shift on the next clock.
      PORTB &= ~(1 << KEY_CLOCK_PIN);

      if(FREQUENCIES[freq_index]) {
        const uint8_t input = (~PINB) & (1 << KEY_INPUT_PIN);
        if(control) {
          if(input && !control_pressed) {
            set_mode(freq_index);
            control_pressed = 1;
          }
        } else {
          const uint8_t current = state & mask;
          if(input && !current) {
            press_key(freq_index);
            state |= mask;
          } else if(!input && current) {
            release_key(freq_index);
            state &= ~mask;
          }
        }
      }

      // Pull clock high to cause a shift.
      PORTB |= 1 << KEY_CLOCK_PIN;

      freq_index += 1;
    }
    if(!control) key_state[i] = state;
  }
  if(!control) control_pressed = 0;

  // Pull load enable low to load new values.
  PORTB &= ~(1 << KEY_LATCH_PIN);
}

static void init()
{
  uint8_t i;
  for(i = 0; i < VOICE_COUNT; i++) {
    voices[i].freq_index = 0;
    voices[i].freq = 0;
  }
  for(i = 0; i < KEY_BYTES; i++) {
    key_state[i] = 0;
  }
  instrument = 0;
  tuning = INITIAL_TUNING;
  control_pressed = 0;
}

int main()
{
  cli();

  // Clock prescalar
  // Default is 1MHz, switch to 8MHz
  CLKPR = 1 << CLKPCE;
  CLKPR = 0;

  // Set input pullups and output state.
  PORTB = (1 << FUN_INPUT_PIN);

  // Set outputs.
  DDRB = (1 << KEY_LATCH_PIN)
       | (1 << KEY_CLOCK_PIN)
       | (1 << AUDIO_OUT_PIN);

  // PWM timer setup (timer1)
  PLLCSR = (1 << PCKE) | (1 << PLLE);   // 64MHz PLL source for timer1
  TIMSK = 0;                            // Timer interrupts off
  TCCR1 = 1 << CS10;                    // 1:1 prescalar
  GTCCR = (1 << PWM1B) | (2 << COM1B0); // PWM B, Clear on match
  OCR1C = 255;                          // Divide by 256 -> 250 kHz
  OCR1B = 0;                            // Duty cycle
  
  // Tone generator timer setup (timer0)
  // Clock is 8MHz, set prescaler to 8 and divide by 80 to get 12.5kHz
  TCCR0A = 3 << WGM00;                  // Fast PWM
  TCCR0B = (1 << WGM02) | (2 << CS00);  // Waveform, divide by 8
  OCR0A = 80 - 1;                       // Divide by 80.
  TIMSK = 1 << OCIE0A;                  // Enable compare match interrupt

  init();

  sei();

  for(;;) {
    scan();
  }

  return 0;
}

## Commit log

2023-01-09 Update key sizes.
    [keybed.scad]
2023-01-11 Sensor v0
    [sensor.kicad_pcb, sensor.kicad_sch]
2023-01-12 Update keybed.
    [keybed.scad]
2023-01-21 Move hole
    [keybed.scad]
2023-01-22 Boards ordered.
    [controller.kicad_pcb, controller.kicad_sch, keybed.scad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]
2023-01-22 Move stuff around.
    [keybed.scad]
2023-02-27 Better tolerances.
    [keybed.scad]
2023-03-19 Add STLs.
    [bed.stl, keys.stl, tool.stl]
